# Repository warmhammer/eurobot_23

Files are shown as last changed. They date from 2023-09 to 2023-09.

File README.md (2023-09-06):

# Репозиторий команды Defective Pie на Eurobot Open 2023
## Разработку вели:
* [Попов Максим](https://github.com/warmhammer) (Tech Lead)
* [Данилов Валерий](https://github.com/ArcherBTD) (Embedded / STM32)
* [Норматов Музаффар](https://github.com/mnormatov2001) (Computer Vision)

### По мотивам разработки мы защищали дипломы бакалавра:
* [Планирование движений робота в соревнованиях “Евробот”](https://docs.google.com/presentation/d/1fr5g8CXUArKWf3GTjmxWFYFV9tfaEbzRI8hKjw0zdxc/edit?usp=sharing)
* [Мобильный робот для соревнований "Евробот"](https://disk.yandex.ru/d/c4PaddmryqoMPg)
* [Управление группой мобильных роботов с использованием системы технического зрения](https://drive.google.com/file/d/1nxk7QWcqGhzuHf2DICc2YA-zhSsg4LF9/view?usp=sharing)

### По вопросам писать:
* tg: @wrmhmmr
* e-mail: max.popov.02@ya.ru

# Статус разработки
Команда разъехалась по разным городам и разработка закончилась.

### Успели сделать
* Поднять ROS
* Описать робота в UDRF
* Настроить связь с STM, написать драйверы для BLDC двигателей и запустить ROS контроллеры движения
* Поднять карту и стандартный планер маршрутов
* Поднять интерфейс конечных автоматов

### Не успели сделать
* Поднять локализацию (колесная одометрия не в счет)
* Разработать систему предотвращения столкновений
* Написать конечные автоматы
* Идеально настроить `move_base`, скорее всего нужно писать свой стек навигации
* Отладить и отдебажить

-------

# Главы для разработчиков

1. [Настройка системы](#Настройка-системы)
    1. [Подключение к роботу по SSH](#Подключение-к-роботу-по-SSH)
    2. [VSCode и SSH](#VSCode-и-SSH)
    3. [Настройка ROS Multiple machines](#Настройка-ROS-Multiple-machines)
    4. [Импорт проекта STM32](#Импорт-проекта-STM32)
2. [Работа в системе](#Работа-в-системе)
    1. [Экспорт URDF в RVIZ](#Экспорт-URDF-в-RVIZ)

# Настройка системы
## Подключение к роботу по SSH
0) Если вы используете виртуальную машину, то сеть нужно настроить через мост.
1) На обоих системах (робот и ваш компьютер) внести изменения в `/etc/hosts` (скорее всего надо использовать sudo)
```
local-ip-pc     pc-name
local-ip-robot  robot-name
```
Например
```
192.168.1.8   maxim
192.168.1.12  orangepi4-lts
```

Свой ip можно узнать, например, через ifconfig (должен начинаться на 192.168), ifconfig надо установить. ip робота узнается либо подключением робота к компьютеру, либо в настройке роутера, либо ***у товарищей***. ip меняется на разных роутерах.

2) Если все настроено верно, то получится подключится к роботу так:

```
ssh robot-user-name@robot-name
```
Например

```
ssh orangepi@orangepi4-lts
```
После чего система может задать вопрос про fingerprint, ответить yes. Далее ввести пароль робота и пользоваться им.

3) **БОНУС:** подключение по хэш-ключу. Генерируем сам ключ: 
```
ssh-keygen  # Читаем то, что пишет утилита
``` 
Не советую менять путь файла, по которму записывается ключ! Далее подключаемся по SSH с копированием ключа:
```
ssh-copy-id robot-user-name@robot-name
```
Всё!

## VSCode и SSH
VSCode умеет дружить с SSH. Это удобно, т.к. по SSH очень плохо отрисовываются графические интерфейсы (он для этого просто не создан). Чтобы копаться в файлах робота через SSH надо всего лишь:
1) Скачать дополнение Remote Development от Microsoft
2) Добавить цель (ssh target во вкладке Remote Expoler). Та же команда, что и обычно.
3) Указать ssh конфиг. У меня это `/home/user-name/.ssh/config`. Сам VSCode предложит варанты. В этом пункте могут быть проблемы, если у SSH поменять порт, но мы пока ничего не меняем.

## Настройка ROS Multiple machines
0) Проверить, что правильно внесены найстройки в `/etc/hosts` (прошлый пункт)
1) На обоих машинах внести изменения в `~/.bashrc` (это конфиг bash терминала, надеюсь вы сидите на ubuntu...). То есть изменения возникнут только после перезагрузки терминала.
```
# Строка отвечает за настройку bash под ROS. Так у вас будут сразу работать ROS-команды и выгрузятся ROS-переменные 
source /opt/ros/noetic/setup.bash 

# ROS-переменные для настройки multiple machines
ROS_MASTER_URI=http://master_name:11311/
ROS_HOSTNAME=machine_name
ROS_IP=machine_ip
```
Мы настраиваем так, чтобы ваш компьютер был мастером (он создает roscore, на нем запускаются все "тяжелые" ноды). Поэтому на вашем пк `machine_name` и `master_name` совпадают. На всех машинах `master_name` одинаковый. `machine_name` - имя вашего ПК, у меня это `ROS_HOSTNAME=maxim`. Проверьте, чтобы ROS_IP совпадали с теми, что написаны в `hosts`. Пример с orangepi:
```
ROS_MASTER_URI=http://maxim:11311/
ROS_HOSTNAME=orangepi4-lts
ROS_IP=192.168.1.12
```
2) Если все настроено верно, то запустите на вашем компьютере `roscore`. Тогда команда `rostopic list` на роботе должна показать запущенные топики.

## Импорт проекта STM32
0) С официального сайта установить CUBE IDE россиянам просто так не получится. Чтобы получить bash-скрипт установки либо зайдите на сайт через VPN (или TOR), либо попросите его у товарищей.
1) Для начала надо стянуть изменения из удаленного репозитория. При входе в CUBE IDE выберите в качестве workspace папку проекта. У нас это `eurobot_23`. 
2) Далее `File -> New -> STM32 Project from an Existing STM32CubeMX Configuration File (.ioc)`. Выберите `.ioc` файл (лежит в корне проекта) из импортируемого проекта (например, Eurobot2023). Должен подгрузиться искомый проект.
3) Если при сборке проекта возникла ошибка (или похожая): 
```
arm-none-eabi-gdb: error while loading shared libraries: libncurses.so.5: cannot open shared object file: No such file or directory
```
то необходимо поставить следующую библиотечку:
```
sudo apt install libncurses5
```

# Работа в системе
## Экспорт URDF в RVIZ
0) Устанавливаем экспортер для SolidWorks (у нас 21 версия). https://wiki.ros.org/sw_urdf_exporter
1) Экспортируем архив с urdf (сохраняя настройки с диска). Архив должен называться `dolly_description.zip`
2) Переносим архив на Linux. Запускаем скрипт преобразования архива (находясь в папке проекта):
```
./scripts/description_archive_parsep.py [путь_до_архива]
```
Если так не запускается, то скорее всего у парсера нет прав. Надо дать:
```
chmod +x ./scripts/description_archive_parsep.py
```

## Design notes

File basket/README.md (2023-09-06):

Файл автозапуска на RPI находится тут: /etc/xdg/lxsession/LXDE-pi/autostart

Если автозапуска не произошло, то надо вбить следующие команды:
```
export DISPLAY=:0
eurobot_23/basket/basket_autorun.sh   # запуск bash скрипта
```

Вероятно, если вы вбиваете комадны не по SSH, то export не нужен.

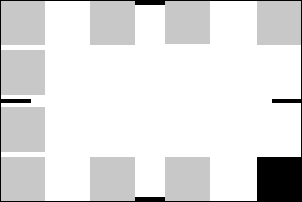
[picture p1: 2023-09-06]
catkin_ws/src/dolly_navigation/maps/friendly_map.png

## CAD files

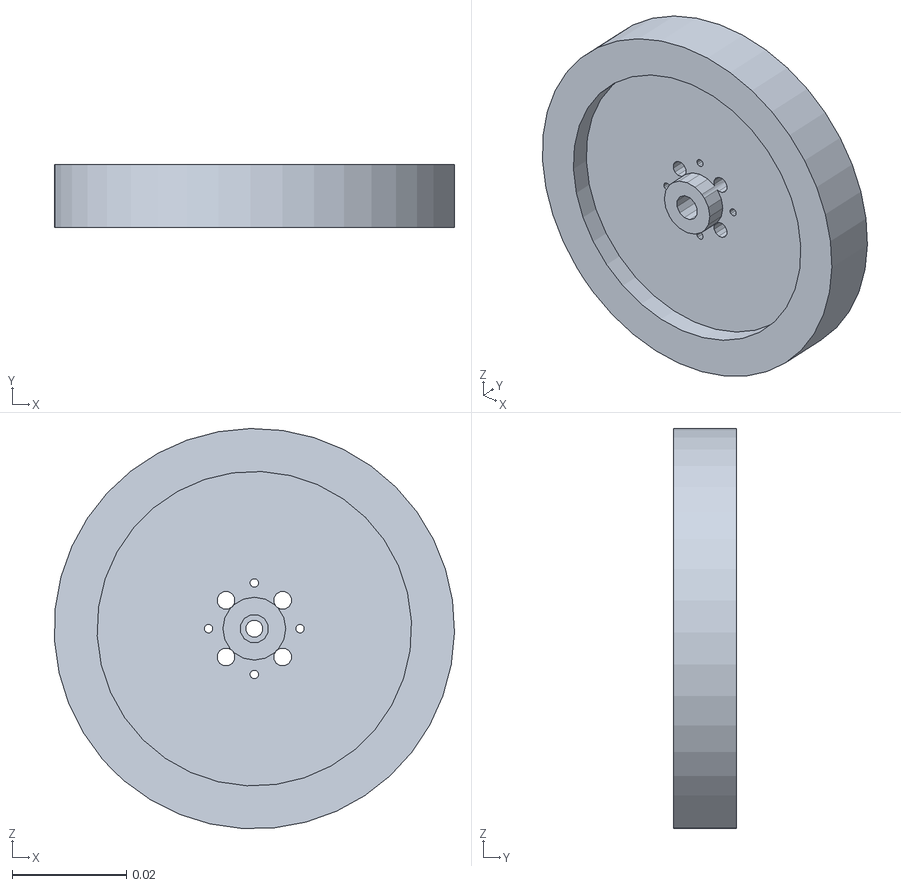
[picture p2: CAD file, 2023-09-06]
catkin_ws/src/dolly_description/meshes/left_wheel.STL
0.0699 x 0.011 x 0.0699

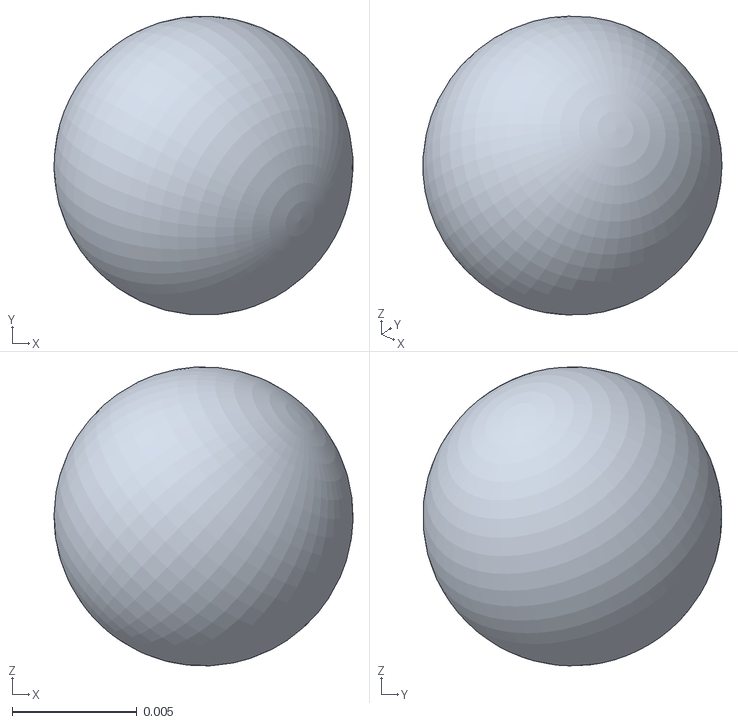
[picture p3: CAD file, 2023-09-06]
catkin_ws/src/dolly_description/meshes/back_caster.STL
0.012 x 0.012 x 0.012

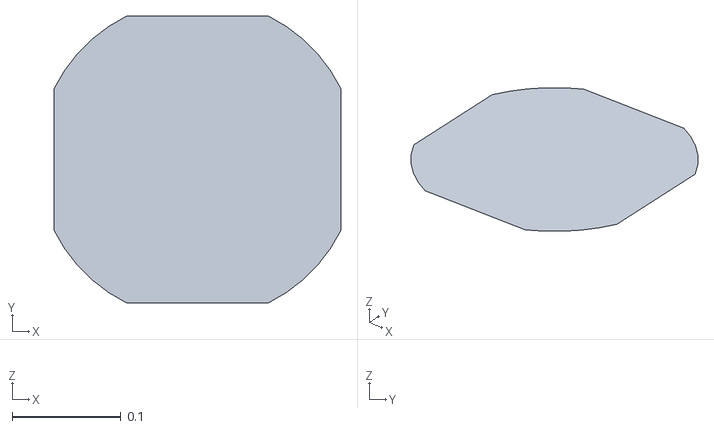
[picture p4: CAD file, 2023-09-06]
catkin_ws/src/dolly_description/meshes/base_footprint.STL
0.264 x 0.264 x 0

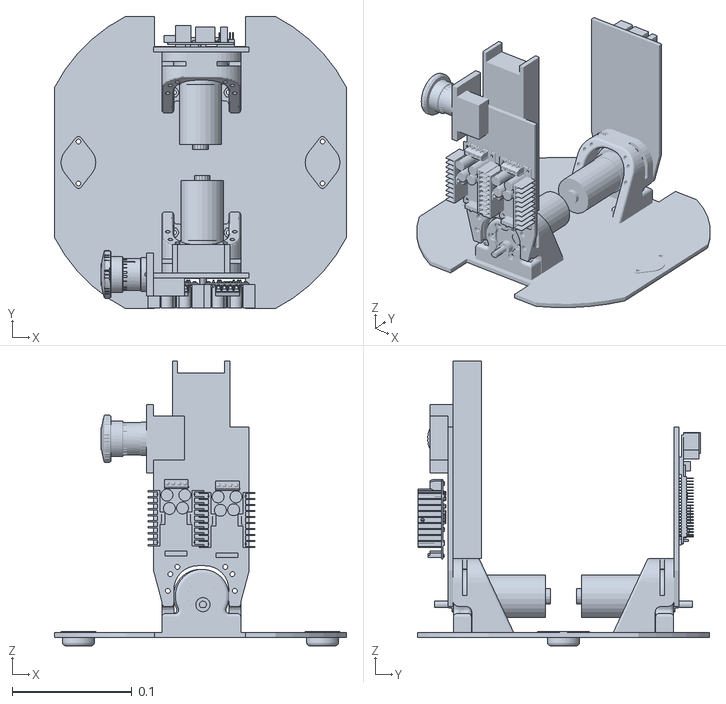
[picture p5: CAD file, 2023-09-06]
catkin_ws/src/dolly_description/meshes/base_link.STL
0.244 x 0.244 x 0.238

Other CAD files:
catkin_ws/src/dolly_description/meshes/front_caster.STL
catkin_ws/src/dolly_description/meshes/right_wheel.STL

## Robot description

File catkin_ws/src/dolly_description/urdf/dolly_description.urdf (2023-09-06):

<robot name="dolly_description">
  <link name="base_footprint">
    <visual>
      <origin xyz="0 0 0" rpy="0 0 0" />
      <geometry>
        <mesh filename="package://dolly_description/meshes/base_footprint.STL" />
      </geometry>
      <material name="">
        <color rgba="0 0 1 1" />
      </material>
    </visual>
    <collision>
      <origin xyz="0 0 0" rpy="0 0 0" />
      <geometry>
        <mesh filename="package://dolly_description/meshes/base_footprint.STL" />
      </geometry>
    </collision>
  </link>
  <link name="base_link">
    <inertial>
      <origin xyz="-0.00036303 -0.0064784 0.029771" rpy="0 0 0" />
      <mass value="3.2695" />
      <inertia ixx="0.0070458" ixy="3.5192E-06" ixz="-8.7066E-07" iyy="0.0077407" iyz="-1.1699E-06" izz="0.01347" />
    </inertial>
    <visual>
      <origin xyz="0 0 0" rpy="0 0 0" />
      <geometry>
        <mesh filename="package://dolly_description/meshes/base_link.STL" />
      </geometry>
      <material name="">
        <color rgba="0.79216 0.81961 0.93333 1" />
      </material>
    </visual>
    <collision>
      <origin xyz="0 0 0" rpy="0 0 0" />
      <geometry>
        <mesh filename="package://dolly_description/meshes/base_link.STL" />
      </geometry>
    </collision>
  </link>
  <joint name="base_link_to_footprint" type="fixed">
    <origin xyz="0 0 0.00751182436050394" rpy="0 0 0" />
    <parent link="base_footprint" />
    <child link="base_link" />
    <axis xyz="0 0 0" />
  </joint>
  <link name="left_wheel">
    <inertial>
      <origin xyz="4.3368E-19 -2.403E-05 3.4694E-18" rpy="0 0 0" />
      <mass value="0.18489" />
      <inertia ixx="7.4493E-05" ixy="7.0054E-22" ixz="-4.5267E-21" iyy="0.00014628" iyz="-8.4037E-22" izz="7.4493E-05" />
    </inertial>
    <visual>
      <origin xyz="0 0 0" rpy="0 0 0" />
      <geometry>
        <mesh filename="package://dolly_description/meshes/left_wheel.STL" />
      </geometry>
      <material name="">
        <color rgba="0 1 0 1" />
      </material>
    </visual>
    <collision>
      <origin xyz="0 0 0" rpy="0 0 0" />
      <geometry>
        <mesh filename="package://dolly_description/meshes/left_wheel.STL" />
      </geometry>
    </collision>
  </link>
  <joint name="left_wheel_to_base" type="continuous">
    <origin xyz="-0.000568807268987122 0.1068 0.0274882756394961" rpy="0 0 0" />
    <parent link="base_link" />
    <child link="left_wheel" />
    <axis xyz="0 -1 0" />
  </joint>
  <link name="right_wheel">
    <inertial>
      <origin xyz="-4.3368E-19 -2.403E-05 -3.4694E-18" rpy="0 0 0" />
      <mass value="0.18489" />
      <inertia ixx="7.4493E-05" ixy="-1.3204E-21" ixz="-3.9575E-21" iyy="0.00014628" iyz="8.3738E-22" izz="7.4493E-05" />
    </inertial>
    <visual>
      <origin xyz="0 0 0" rpy="0 0 0" />
      <geometry>
        <mesh filename="package://dolly_description/meshes/right_wheel.STL" />
      </geometry>
      <material name="">
        <color rgba="0 1 0 1" />
      </material>
    </visual>
    <collision>
      <origin xyz="0 0 0" rpy="0 0 0" />
      <geometry>
        <mesh filename="package://dolly_description/meshes/right_wheel.STL" />
      </geometry>
    </collision>
  </link>
  <joint name="right_wheel_to_base" type="continuous">
    <origin xyz="0.00202133439372744 -0.1068 0.0274882756394961" rpy="3.14159265358979 0 0" />
    <parent link="base_link" />
    <child link="right_wheel" />
    <axis xyz="0 -1 0" />
  </joint>
  <link name="front_caster">
    <inertial>
      <origin xyz="0.204 -1.7008E-18 0" rpy="0 0 0" />
      <mass value="0.00090478" />
      <inertia ixx="1.3029E-08" ixy="-1.4061E-25" ixz="6.3367E-25" iyy="1.3029E-08" iyz="-6.302E-26" izz="1.3029E-08" />
    </inertial>
    <visual>
      <origin xyz="0 0 0" rpy="0 0 0" />
      <geometry>
        <mesh filename="package://dolly_description/meshes/front_caster.STL" />
      </geometry>
      <material name="">
        <color rgba="0.79216 0.81961 0.93333 1" />
      </material>
    </visual>
    <collision>
      <origin xyz="0 0 0" rpy="0 0 0" />
      <geometry>
        <mesh filename="package://dolly_description/meshes/front_caster.STL" />
      </geometry>
    </collision>
  </link>
  <joint name="front_caster_to_base" type="fixed">
    <origin xyz="-0.102 0 -0.004" rpy="0 0 0" />
    <parent link="base_link" />
    <child link="front_caster" />
    <axis xyz="0 0 0" />
  </joint>
  <link name="back_caster">
    <inertial>
      <origin xyz="1.3878E-17 3.3881E-20 8.6736E-19" rpy="0 0 0" />
      <mass value="0.00090478" />
      <inertia ixx="1.3029E-08" ixy="-1.4061E-25" ixz="1.1034E-24" iyy="1.3029E-08" iyz="-1.8513E-25" izz="1.3029E-08" />
    </inertial>
    <visual>
      <origin xyz="0 0 0" rpy="0 0 0" />
      <geometry>
        <mesh filename="package://dolly_description/meshes/back_caster.STL" />
      </geometry>
      <material name="">
        <color rgba="0.79216 0.81961 0.93333 1" />
      </material>
    </visual>
    <collision>
      <origin xyz="0 0 0" rpy="0 0 0" />
      <geometry>
        <mesh filename="package://dolly_description/meshes/back_caster.STL" />
      </geometry>
    </collision>
  </link>
  <joint name="back_caster_to_base" type="fixed">
    <origin xyz="-0.102 0 -0.004" rpy="0 0 0" />
    <parent link="base_link" />
    <child link="back_caster" />
    <axis xyz="0 0 0" />
  </joint>

  <link name="sensors">
    <visual>
      <origin xyz="0 0 0" rpy="0 0 0" />
      <geometry>
          <box size = "0.03 0.03 0.03" />
      </geometry>
    </visual>
  </link>

  <joint name="sensors_to_base" type="fixed">
    <origin xyz="0 0 0" rpy="0 0 0" />
    <parent link="base_link" />
    <child link="sensors" />
    <axis xyz="0 0 0" />
  </joint>

</robot>

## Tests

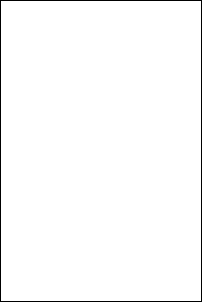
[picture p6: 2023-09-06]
catkin_ws/src/dolly_navigation/maps/test_map.png

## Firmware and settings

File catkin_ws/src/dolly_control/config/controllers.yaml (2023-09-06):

joint_state_controller:
  type: joint_state_controller/JointStateController
  publish_rate: 100
  
mobile_base_controller:
  type: "diff_drive_controller/DiffDriveController"
  left_wheel: 'left_wheel_to_base'
  right_wheel: 'right_wheel_to_base'
  publish_rate: 100
  pose_covariance_diagonal: [0.001, 0.001, 1000000.0, 1000000.0, 1000000.0, 1000.0]
  twist_covariance_diagonal: [0.001, 0.001, 1000000.0, 1000000.0, 1000000.0, 1000.0]
  wheel_separation: 0.217 # 0.217
  wheel_radius: 0.035 # 70
  wheel_separation_multiplier: 1.0 # default: 1.0
  wheel_radius_multiplier    : 1.0 # default: 1.0
  cmd_vel_timeout: 0.25
  base_frame_id: base_footprint
  linear:
    x:
      has_velocity_limits : true
      max_velocity : 1.56 # m/s
      has_acceleration_limits: true
      max_acceleration : 6.0 # m/s^2
  angular:
    z:
      has_velocity_limits : true
      max_velocity : 13.31 # rad/s
      has_acceleration_limits: true
      max_acceleration : 9.42 # rad/s^2
  # enable_odom_tf: true
  odom_frame_id: odom
  # publish_cmd: true

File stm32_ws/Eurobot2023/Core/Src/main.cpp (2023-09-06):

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
/* Includes ------------------------------------------------------------------*/
#include "main.h"
#include "dma.h"
#include "i2c.h"
#include "tim.h"
#include "usart.h"
#include "gpio.h"

/* USER CODE BEGIN Includes */
#include "ros.h"

#include "motors.h"
#include "wrappers.h"
#include "servo/servo_interface.h"
#include "range_sensor/range_sensor_interface.h"

#include "utils/start_button.h"

/* USER CODE END Includes */


/* USER CODE BEGIN PV */

//------------------------------------------------define EncoderMotors perif BEGIN--------------------
#define dir_port_l 				GPIOA
#define dir_pin_l 				GPIO_PIN_8

#define ena_port  				GPIOA
#define ena_pin 				GPIO_PIN_10

#define	encoder_timer_l 		&htim2
#define encoder_timer_chanel1_l TIM_CHANNEL_3

#define speed_timer_l 			&htim3
#define speed_timer_chanel2_l  	TIM_CHANNEL_3

#define pwm_timer_l				&htim9
#define pwm_timer_chanel1_l  	TIM_CHANNEL_1

#define dir_port_r 				GPIOA
#define dir_pin_r				GPIO_PIN_9

#define	encoder_timer_r 		&htim5
#define encoder_timer_chanel1_r TIM_CHANNEL_2

#define speed_timer_r 			&htim4
#define speed_timer_chanel2_r  	TIM_CHANNEL_2

#define pwm_timer_r				&htim12
#define pwm_timer_chanel1_r  	TIM_CHANNEL_1

//------------------------------------------------define EncoderMotors perif END--------------------

//------------------------------------------------define Range_Sensors perif BEGIN------------------

//------------------------------------------------define Range_Sensors perif END--------------------



/* USER CODE END PV */

void SystemClock_Config(void);
/* USER CODE BEGIN 0 */

//----------------------------------------------------------------ROS------------------------------------

ros::NodeHandle node;

//-------------------------------------------------------------------------------------------------------

//------------------------------------------------------------GLOBAL OBJ---------------------------------

motors::EncoderMotor left_encoder_motor (
    {dir_port_l, dir_pin_l},
    {ena_port, ena_pin},
    {encoder_timer_l, encoder_timer_chanel1_l},
    {speed_timer_l, speed_timer_chanel2_l},
    {pwm_timer_l, pwm_timer_chanel1_l},
	false,
	node,
	"/dolly/left_wheel/angle32",
	"/dolly/left_wheel/cur_vel32",
	"/dolly/left_wheel/pwd32"
);

motors::EncoderMotor right_encoder_motor (
    {dir_port_r, dir_pin_r},
    {ena_port, ena_pin},
    {encoder_timer_r, encoder_timer_chanel1_r},
    {speed_timer_r, speed_timer_chanel2_r},
    {pwm_timer_r, pwm_timer_chanel1_r},
//	true,
	false,
	node,
	"/dolly/right_wheel/angle32",
	"/dolly/right_wheel/cur_vel32",
	"/dolly/right_wheel/pwd32"
);

//-----------------------------------------------------------Servos------------------------------

// ****** constexpr is used here to avoid logic error at compile time
constexpr servo_description::RDS3225_Servo left_gripper(0, 60, 130);
constexpr servo_description::RDS3225_Servo right_gripper(1, 55, 125);
constexpr servo_description::RDS3225_Servo lift(2, 15, 210);
constexpr servo_description::RDS3225_Servo plunger(3, 95, 150);

constexpr servo_description::PDI_6225MG_300_Servo left_limiter(4); // 55, 105
constexpr servo_description::PDI_6225MG_300_Servo right_limiter(5); // 180, 230
constexpr servo_description::PDI_6225MG_300_Servo cherry_spreader(6, 10, 285);
constexpr servo_description::PDI_6225MG_300_Servo cherry_separator(7, 115, 240);
constexpr servo_description::PDI_6225MG_300_Servo visor(8, 10, 235);

servo_interface::Servo_Interface servos(
	{
		left_gripper,
		right_gripper,
		lift,
		plunger,

		left_limiter,
		right_limiter,
		cherry_spreader,
		cherry_separator,
		visor

	},
	node,
	"servo_cmd_topic"
);

//-----------------------------------------------------------Range_Sensors-----------------------

rs_interface::VL53L0X_Interface range_sensors (
	{
		{{XSHUT_1_GPIO_Port, XSHUT_1_Pin}},
		{{XSHUT_2_GPIO_Port, XSHUT_2_Pin}},
		{{XSHUT_3_GPIO_Port, XSHUT_3_Pin}},
		{{XSHUT_4_GPIO_Port, XSHUT_4_Pin}},
		{{XSHUT_5_GPIO_Port, XSHUT_5_Pin}},
		{{XSHUT_6_GPIO_Port, XSHUT_6_Pin}},
		{{XSHUT_7_GPIO_Port, XSHUT_7_Pin}}
	},
	node,
	"range_sensors_topic"
);

//-----------------------------------------------------------Utils-------------------------------

utils::StartButton start_button(
	{START_BUTTON_GPIO_Port, START_BUTTON_Pin},
	node,
	"start_topic"
);

//------------------------------------------------------------SYSTEM UART func-------------------

void HAL_UART_ErrorCallback(UART_HandleTypeDef *huart){

    uint8_t data[1];
  __HAL_UART_CLEAR_OREFLAG(huart);
  __HAL_UART_CLEAR_NEFLAG(huart);
  __HAL_UART_CLEAR_FEFLAG(huart);

  /* Disable the UART Error Interrupt: (Frame error, noise error, overrun error) */
  __HAL_UART_DISABLE_IT(huart, UART_IT_ERR);
  //The most important thing when UART framing error occur/any error is restart the RX process
  //Restarting the RX, .. 1 byte. .. u8DATUartShortRxBuffer is My own rx buffer
    HAL_UART_Receive_IT(huart, data, 1);
}

void UART_check(UART_HandleTypeDef *huart){
    if (__HAL_UART_GET_FLAG(huart, UART_FLAG_ORE) != RESET){
		__HAL_UART_CLEAR_OREFLAG(huart);
		__HAL_UART_ENABLE_IT(huart,UART_IT_ERR);

		if (__HAL_UART_GET_FLAG(huart,UART_FLAG_RXNE) == SET){
			huart->Instance->CR3 |= 1 << 6;
			huart->Instance->CR3 |= 1 << 7;
		}
	}
}

//------------------------------------------------------------SYSTEM Transmit CallBack's-------------------

void HAL_UART_TxCpltCallback(UART_HandleTypeDef *huart) {
    node.getHardware()->flush();
}

void HAL_UART_RxCpltCallback(UART_HandleTypeDef *huart) {
    node.getHardware()->reset_rbuf();
}

//------------------------------------------------------------TIM SYSTEM Motors CallBack's-------------------
void HAL_TIM_PeriodElapsedCallback(TIM_HandleTypeDef* htim) {
	left_encoder_motor.__set_velocity_to_null__(htim);
	right_encoder_motor.__set_velocity_to_null__(htim);
}

//--------------------------------------------------------------------------------------------------------

/* USER CODE END 0 */

/**
  * @brief  The application entry point.
  * @retval int
  */
int main(void)
{
  /* MCU Configuration--------------------------------------------------------*/

  /* Reset of all peripherals, Initializes the Flash interface and the Systick. */
  HAL_Init();

  /* Configure the system clock */
  SystemClock_Config();

  /* Initialize all configured peripherals */
  MX_GPIO_Init();
  MX_DMA_Init();
  MX_I2C1_Init();
  MX_I2C2_Init();
  MX_TIM2_Init();
  MX_TIM5_Init();
  MX_TIM12_Init();
  MX_TIM3_Init();
  MX_TIM4_Init();
  MX_TIM9_Init();
  MX_USART2_UART_Init();
  /* USER CODE BEGIN 2 */

    //-------------------------------------------------------------ROS----------------------

    node.initNode();

    while (node.connected() == false) {
        // waiting for connection
        UART_check(&huart2);
    	HAL_Delay(1);
    	node.spinOnce();
    }
   //-----------------------------------------------------------ROS::Init_begin------------

    left_encoder_motor.init();
    right_encoder_motor.init();

//    servos.init(&hi2c1);

//    range_sensors.init(&hi2c2);

//    start_button.init();

//    HAL_Delay(3000);

   //-----------------------------------------------------------ROS::Init_end--------------
    node.getHardware()->flush();	// buffer flush

  /* USER CODE END 2 */

  /* Infinite loop */
  /* USER CODE BEGIN WHILE */

    auto prev = HAL_GetTick();

    while (1) {
        if (node.connected() == true) {
            auto now = HAL_GetTick();

            if (now - prev >= 15) {
                prev = now;

                right_encoder_motor.publish();
                left_encoder_motor.publish();

//                range_sensors.publish();

//                start_button.publish();

            }
        }

        UART_check(&huart2);

        HAL_Delay(1);
        node.spinOnce();

    /* USER CODE END WHILE */

    /* USER CODE BEGIN 3 */
    }
  /* USER CODE END 3 */
}

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


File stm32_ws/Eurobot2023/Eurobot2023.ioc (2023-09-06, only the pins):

Mcu.UserName=STM32F407VGTx
PA0-WKUP.Signal=S_TIM5_CH1
PA1.Signal=S_TIM5_CH2
PA10.GPIO_Label=ENA
PA10.Signal=GPIO_Output
PA2.Signal=S_TIM2_CH3
PA5.Signal=S_TIM2_CH1_ETR
PA6.Signal=S_TIM3_CH1
PA8.GPIO_Label=DIR_L
PA8.Signal=GPIO_Output
PA9.GPIO_Label=DIR_R
PA9.Signal=GPIO_Output
PB0.Signal=S_TIM3_CH3
PB10.Signal=I2C2_SCL
PB11.Signal=I2C2_SDA
PB14.Signal=S_TIM12_CH1
PB6.Signal=I2C1_SCL
PB7.Signal=I2C1_SDA
PC1.GPIO_Label=XSHUT_1
PC1.Signal=GPIO_Output
PC2.GPIO_Label=XSHUT_2
PC2.Signal=GPIO_Output
PC3.GPIO_Label=XSHUT_3
PC3.Signal=GPIO_Output
PD12.Signal=S_TIM4_CH1
PD13.Signal=S_TIM4_CH2
PD5.Signal=USART2_TX
PD6.Signal=USART2_RX
PE0.GPIO_Label=START_BUTTON
PE0.Signal=GPIO_Input
PE11.GPIO_Label=XSHUT_6
PE11.Signal=GPIO_Output
PE14.GPIO_Label=XSHUT_7
PE14.Signal=GPIO_Output
PE5.Signal=S_TIM9_CH1
PE7.GPIO_Label=XSHUT_4
PE7.Signal=GPIO_Output
PE9.GPIO_Label=XSHUT_5
PE9.Signal=GPIO_Output
PH0-OSC_IN.Signal=RCC_OSC_IN
PH1-OSC_OUT.Signal=RCC_OSC_OUT

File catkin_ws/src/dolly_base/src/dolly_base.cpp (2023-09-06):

#include <ros/ros.h>

#include <ros/callback_queue.h>

#include "dolly_hardware_interface.hpp"

void controlLoop(dolly_hw::DollyHW& hardware, controller_manager::ControllerManager& cm, ros::Time& prev_time) {
	ros::Time cur_time = ros::Time::now();
	ros::Duration delta_time = cur_time - prev_time;
	prev_time = cur_time;

    hardware.read(delta_time);
	cm.update(cur_time, delta_time);
	hardware.write();
}

int main(int argc, char* argv[]) {
    ros::init(argc, argv, "dolly_base");
	ros::NodeHandle root_node;
	ros::NodeHandle robot_hw_node("~");

    // ros::CallbackQueue callback_queue;
	// ros::AsyncSpinner spinner(1, &callback_queue);

    dolly_hw::DollyHW hardware(root_node, robot_hw_node);
    controller_manager::ControllerManager cm(&hardware, root_node);

    ros::Time begin = ros::Time::now();

    ros::Timer timer = root_node.createTimer (
        ros::Duration(0.01), 
        [&](const ros::TimerEvent&){controlLoop(hardware, cm, begin);}
    );


    // ros::CallbackQueue callback_queue;
	// ros::AsyncSpinner spinner(2, &callback_queue);
    // spinner.start();
    // ros::spin();

    ros::MultiThreadedSpinner spinner(2); // Don't work without multithread. Probably, controller_manager eats full work time
	spinner.spin();

	return 0;
}

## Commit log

2022-08-01 first dolly urdf export from SW2021
    [ASM_Ver_1.SLDASM.csv, ASM_Ver_1.SLDASM.urdf, base.STL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]
2022-08-01 dolly was moved
    [ASM_Ver_1.SLDASM.csv, ASM_Ver_1.SLDASM.urdf, base.STL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]
2022-08-02 dolly v1 urdf update
    [ASM_Ver_1.SLDASM.csv, base.STL, base_link.STL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]
2022-08-02 dolly v1 urdf update: caster added, mistakes corrected
    [back_caster.STL, base_link.STL, dolly.csv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]
2022-09-09 Now dolly description lies in dolly_description, not just in dolly
    [back_caster.STL, base_link.STL, dolly.csv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]
2022-09-12 Added non inertial root link in urdf robot description
    [dolly.urdf]
2022-09-28 controller config changing: beauty commit
    [controllers.yaml]
2022-09-28 rviz vizualization of urdf model with joints manipulating
2022-09-28 dolly_description package is ready: simple rviz driving
    [dolly.urdf]
2022-09-28 controllers package for dolly
    [controllers.yaml]
2022-10-01 modified .gitignore file, added stm32 trash files ignore
2022-10-01 dolly directory deleted
    [ASM_Ver_1.SLDASM.csv, ASM_Ver_1.SLDASM.urdf, base.STL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]
2022-10-02 added new Encoder Motor driver
2022-10-03 debug driver of EncoderMotors
2022-10-04 added Publishers for velocity and position
2022-10-06 controller parameters repair
    [controllers.yaml]
2022-10-07 CallBack review in EncoderMotor class
2022-10-07 changing library subscriber.h: using std::functional for lambda use case
2022-10-07 Encoder motor class lambda-callback possibility
2022-10-07 Publisher review in EncoderMotor class
2022-10-08 publisher and subscriber in EncoderMotor class
2022-10-08 start UART Debug
2022-10-12 fixed subscribers and publishers,added system callbacks,added motors callbacks, control test from other mashine is done
    [Eurobot2023.ioc, main.cpp, motors.cpp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]
2022-10-15 UART connection fixed
2022-10-23 pid regulator coef on left motor is setted
    [controllers.yaml]
2022-10-30 fix vel timer 4
    [Eurobot2023.ioc, main.cpp]
2022-11-05 Update readme: stm32 project import description
2022-11-05 update readme: urdf parser description
2022-11-05 dolly description update and renaming
    [base_footprint.STL, base_link.STL, dolly.csv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]
2022-11-12 EncoderMotor class: getter for cur_velocity and cur_angle. Also _inversed direction added
2022-11-12 EncoderMotor: publishers are inside class
2022-11-13 EncoderMotor class: subscribers inside class
2022-11-13 Wrappers for pins and timers
2022-11-13 Adding interruption TIM3 and TIM4
2022-11-19 Big stm commit: speed_timer now is velocity_timer; DMA for angle_timer; both_edges for velocity and angle timers; motor.h cast mistake solved; clarification of consexpr constants
    [Eurobot2023.ioc, main.cpp, motors.cpp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]
2022-11-26 stm32: bugfix
2023-02-01 added package 'camera_calibration'
2023-02-01 added packages 'aruco_description', 'camera_sim'
    [camera.urdf.xacro, general_aruco.urdf.xacro, general_aruco.xacro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]
2023-02-05 deleted 'calibrate_camera.launch'
2023-02-05 added 'calibrate.launch
2023-02-06 modified calibration config
2023-02-06 modified .gitignore: stop ignoring **/camera_info/
2023-02-12 Some probably fixes for UART, new pca9685 driver, servo description in progress
    [Eurobot2023.ioc, main.cpp, motors.cpp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]
2023-02-18 add servo interface PCA96858
2023-02-20 servo test changes
2023-02-20 UART bugfix, servo interface init fix
    [main.cpp, servo_interface.cpp]
2023-02-22 upgrade Servo class: add initialazer list
2023-02-23 add API layer for VL53L0X range sensor
2023-02-23 add range sensor interface
2023-03-07 testing range sensors commit
2023-03-21 modified aruco description files
    [general_aruco.urdf.xacro, general_aruco.xacro]
2023-03-21 modified camera description file
    [camera.urdf.xacro]
2023-04-02 modified calibrate.launch
2023-04-02 updated calibration data
2023-04-07 servo_trajectory_generator was removed
2023-04-07 servo deascription and interface were refined
2023-04-07 main: adopted for refined servo interface
2023-04-07 pca9685-lib: specific servos were deleted
2023-04-07 servo files reorganization
2023-04-07 motors: changes rolling back
2023-04-07 range sensor: changes rolling back
2023-04-07 main updated for no range sensors
2023-04-17 servo_description: bigfix, pwm_koef and pwm_value editing
2023-04-17 servo_description: became header-only, got input variables compile check, no floats anymore
2023-04-18 remove interrupt pin from configure
2023-04-18 range sensor test configure
2023-04-19 range sensors adress bugfix
2023-04-20 range sensors are work
2023-04-20 added camera_pose_common.py
2023-04-20 added camera_properties.yaml
2023-04-20 added camera_pose_node.py
2023-04-20 added camera_pose_node.py to cmake install_python
2023-04-24 modified camera_pose_node
2023-04-26 refactoring camera_pose_node
2023-04-29 servo_description: bugfix, pwm_koef should be float
    [servo_description.h]
2023-04-29 main: servo limits were added
2023-05-14 modified camera.urdf.xacro simulator file
    [camera.urdf.xacro]
2023-05-14 modified camera_pose_common.py
2023-05-14 modified camera_pose_node.py
2023-05-18 VL53L0X: sensors description and interface
2023-05-19 Night before competition
    [dolly_description.urdf]
2023-05-20 Range sensors: night before competition
2023-05-20 calibration: added cv2.getOptimalNewCameraMatrix()
2023-05-20 calibration: added take_images_node.py
2023-05-20 calibration: modified calibrate.launch
2023-05-20 calibration: updated calibration data
2023-05-20 5 lasers inside
2023-05-20 Main with ranges sensors
2023-05-20 camera_pose_common.py: bugfix
2023-06-06 low_level: ws for stm32, autpgenerated headers and some little stuff
2023-06-06 wheel analisys .py

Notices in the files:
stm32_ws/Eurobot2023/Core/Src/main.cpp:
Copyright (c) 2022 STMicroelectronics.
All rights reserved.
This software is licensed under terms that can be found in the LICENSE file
